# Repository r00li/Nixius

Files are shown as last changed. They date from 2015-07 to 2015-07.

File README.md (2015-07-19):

## Nixius ##
A simple ARM powered Nixie clock.

Nixius

**Features**

 - It's a clock
 - User settable auto turn on/turn off time (can turn off at night)
 - Manual display on/off button
 - Temperature display

**I want it!**

Great! Build it! This project includes everything that you need. A complete PCB, a 3D printable case and firmware source code.

**Instructions**

 1. Download the project
 2. Manufacture the PCB at your favourite PCB fab (I recommend elecrow.com). I've already included the gerbers so you don't even have to use eagle to export them - they are exported for use with elecrow so you may need to export them again if you want to manufacture them somewhere else.
 3. Order the necessary parts listed in bill of materials (I recommend Farnell/Element 14). Nixies themselves can be bought at siberian-shop.com or somewhere else.
 4. Solder everything together
 5. Flash the firmware to the micro. You will need any STM development board (they can be bought at Farnell for less than 10€) with STLINK. You can compile the project using free EmBlocks IDE (now also called EmBitz). It's a GCC based IDE so it should work with other compilers/IDEs as well. If you don't want to compile the project then you can simply used the .hex file in the bin folder. It's configured for use without the temperature sensor. But compiling everything in EmBlocks should only take a few clicks so I recommend that. 
 6. 3D print the case. It's designed to be 3D printable on most popular home 3D printers. 
 7. Assemble everything and enjoy

I am happy to provide any assistance that you may need. 

**More information**

Hackaday.io: https://hackaday.io/project/5543-nixius

My website: http://www.r00li.com

**Tinkering**

I've used many online sources to build this thing. Especially the power supply part and how to drive the Nixies. Do you want to use some of the bits from my design? Go right ahead! Don't want to use IN-1 nixies? You will just need to replace 4 resistors in the center with the correct ones and you'll be fine. And of course use some wire to connect the nixies. 

**License**

Licensed under GNU GPL v3.

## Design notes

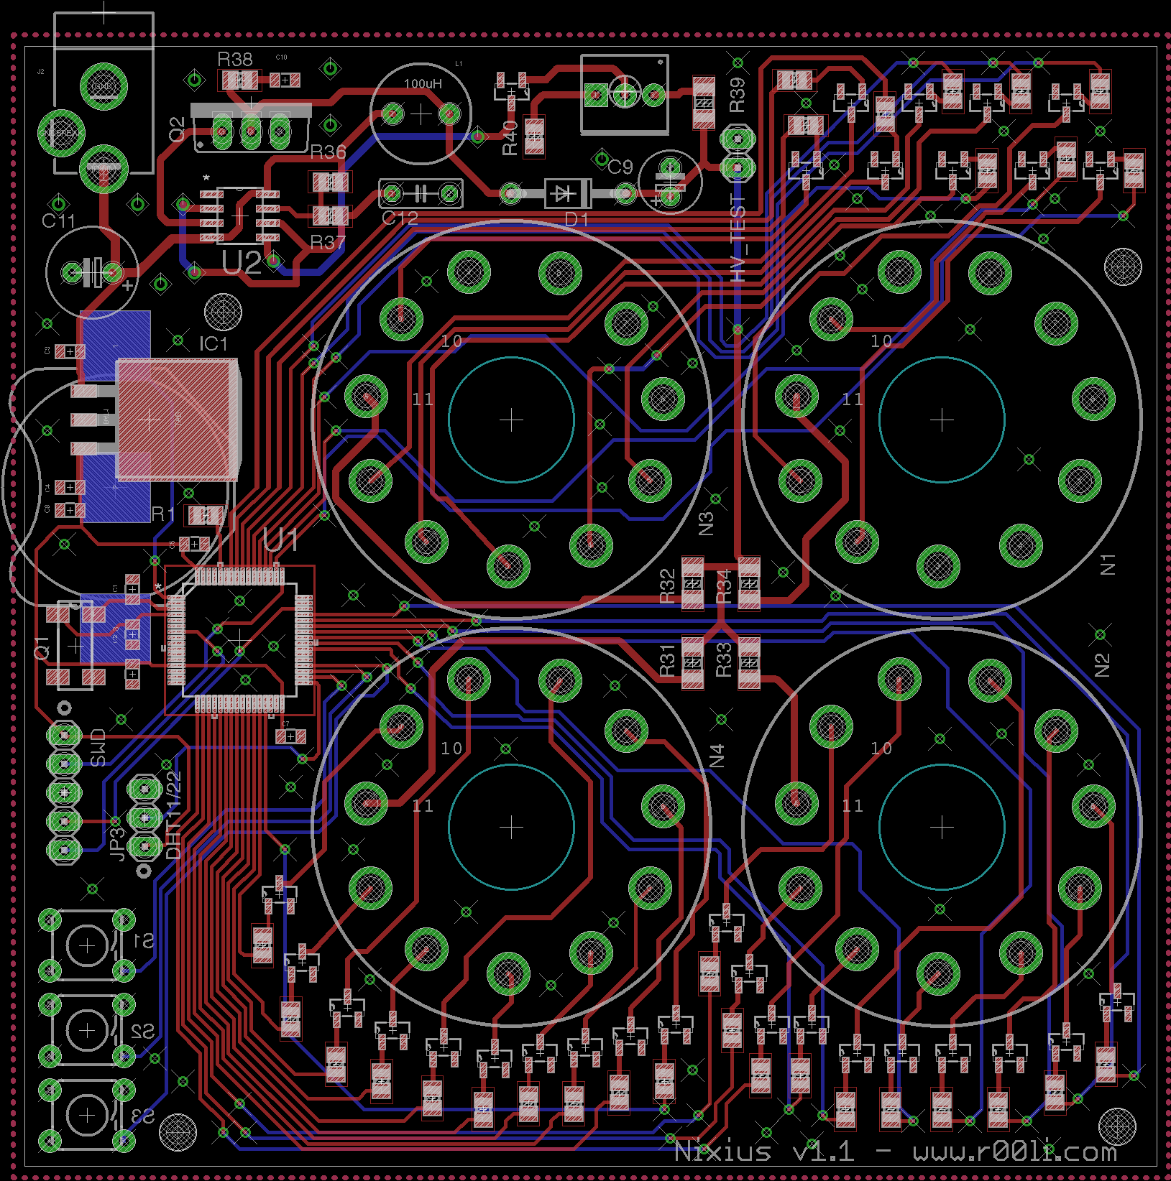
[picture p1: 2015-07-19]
PCB/Nixius_PCB.png

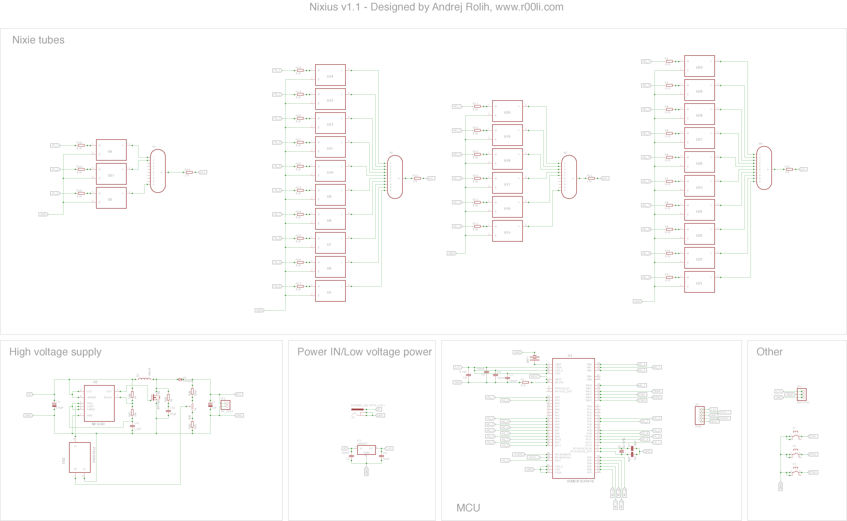
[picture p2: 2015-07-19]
PCB/Nixius.png

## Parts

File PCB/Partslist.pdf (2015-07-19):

Qty | Value | Device | Package | Farnell order code | Parts designators | Description
1 | | SMD Battery holder | 20MM | 2115303 | BAT1 | Battery Holder 20mm
3 | FSM6JH | Switch | TACTILE-‐PTH | 1555983 | S1, S2, S3 | Momentary Switch (through hole) -‐ around 8.5mm height
4 | 100nF | C | 0805 | 1759143 | C3, C5, C6, C7 | Capacitor
1 | 100uH | Inductor | RLB0912 | 1864382 | L1 | Inductor
1 | 10k | R (200V tolerant) | 0805 | 1750767 | R37 | Resistor
1 | 10uF | C | 0805 | 2362101 | C4 | Capacitor
2 | 18pF | C | 0805 | 1740651 | C1, C2 | Capacitor
2 | 1k | R (200V tolerant) | 0805 | 1750754 | R36, R38 | Resistor
1 | 1k | Trimpot (200V tolerant) | 3362U-‐2 | 1141401 | R35 | Trimmer potentiometer
1 | 1uF | C (200V tolerant) | E2,5-‐6 | 2346640 | C9 | Capacitor
1 | 2.2nF | C (200V tolerant) | 050-‐025X075 | 1166065 | C12 | Capacitor
1 | 220k | R (200V tolerant) | 1206 | 2352636 | R39 | Resistor
4 | 27k | R (200V tolerant) | 1206 | 1750855 | R31, R32, R33, R34 | Resistor
1 | 32.7kHZ | Crystal | MC-‐306 | 1712823 | Q1 | Crystal
1 | 4.7uF | C | 0805 | 1759414 | C8 | Capacitor
1 | 470uF | C | E3,5-‐8 | 1907237 | C11 | Capacitor
1 | 47pF | C (200V tolerant) | 0805 | 1284128 | C10 | Capacitor
2 | 510 | R | 0805 | 9334637 | R1, R40 | Resistor
29 | 8.2k | R | 0805 | 2074518 | R2, R3, R4, R5, R6, R7, R8, R9, R10, R11, R12, R13, R14, R15, R16, R17, R18, R19, R20, R21, R22, R23, R24, R25, R26, R27, R28, R29, R30 | Resistor -‐ Parts designators on PCB have been removed
1 | DHT11/22 | Temperature sensor | | / | JP3 | Temperature sensor -‐ DHT11/DHT22 -‐ Optional -‐ You can get it at elecrow
30 | FMMTA42 | FMMTA42 | SOT23 | 9526277 | U3, U4, U5, U6, U7, U8, U9, U10, U11, U12, U13, U14, U15, U16, U17, U18, U19, U20, U21, U22, U23, U24, U25, U26, U27, U28, U29, U30, U31, U32 | NPN Silicon planar high voltage transistor -‐ Parts designators on PCB have been removed
4 | IN-‐1 | IN-‐1 | | / | N1, N2, N3, N4 | IN-‐1: large numeric topview nixie tube -‐ I used Siberian shop (http://www.siberian-‐shop.com/)
1 | IRF730 | IRF730 | TO220 | 8648433 | Q2 | N-‐channel MOSFET
1 | LM2937 | LM2937 | TO263-‐3 | 1469066 | IC1 | LM2937-‐3.3V Voltage regulator
1 | NE555D | NE555D | SOIC8 | 9589880 | U2 | Timer
1 | | POWER_JACKPTH_LOCK | | 1608727 | J2 | Power Jack (standard one, through hole -‐ found anywhere)
1 | STM32F051R4T6 | STM32F051R4T6 | LQFP-‐64 | 2115069 | U1 | MCU, 32BIT, ARM CORTEX-‐M0, 64LQFP
1 | | Header | 1X05 | 9733400 | JP1 | Header (you can probably get them cheaper on ebay) -‐ used for programming
1 | UF4004 | UF4004 | DO41-‐10 | 1467502 | D1 | Diode

You

will

also

need:
-‐

Power

supply

(9V).

Farnell

order

code:

2451882
-‐

PCB

manufacturer.

I

always

use

Elecrow

(http://www.elecrow.com/)

Approximate

cost:
Electronic

components

(without

nixies

and

power

supply)

=

around

40€

(+5€

shipping)
Nixies

=

around

10€

(+20€

shipping)
PCB

Manufacture

=

around

15€

(+15€

shipping)
Temperature

sensor

=

around

7€

(shipping

included

with

PCB

manufacture)
Power

supply

=

around

9€

(shipping

included

with

electronic

components)

Total

cost

=

around

80€

(around

120€

with

shipping)

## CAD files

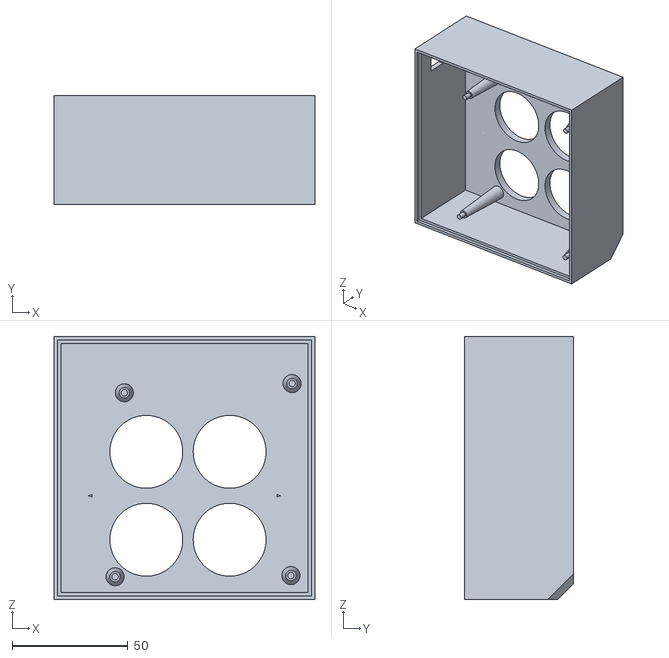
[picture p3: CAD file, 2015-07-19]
Case/Nixius_case.stl
112.8 x 47.3 x 113.8

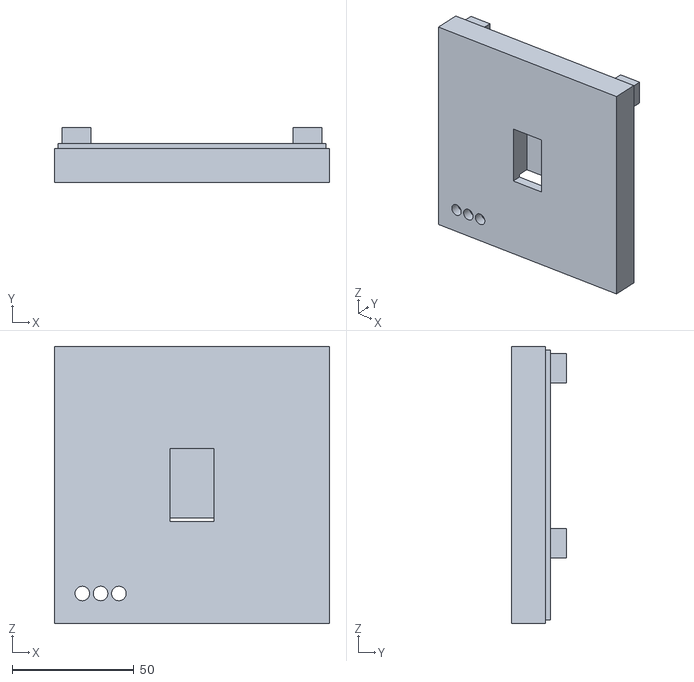
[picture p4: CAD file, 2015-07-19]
Case/Nixius_back.stl
112.8 x 22.5 x 113.8

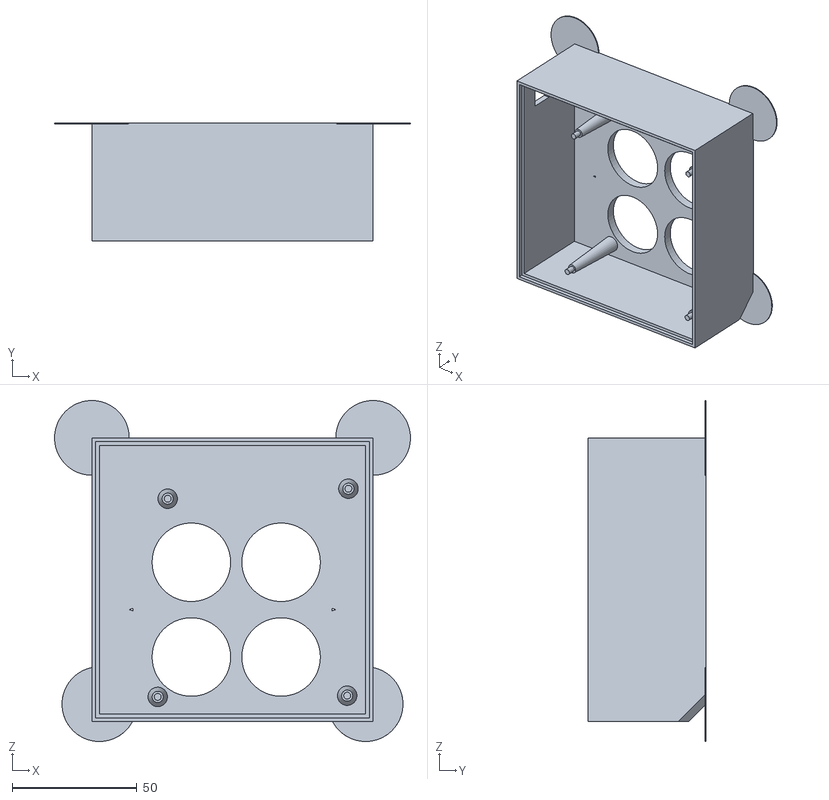
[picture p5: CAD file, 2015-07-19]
Case/Nixius_case_mouse_ears.stl
142.8 x 47.3 x 136.8

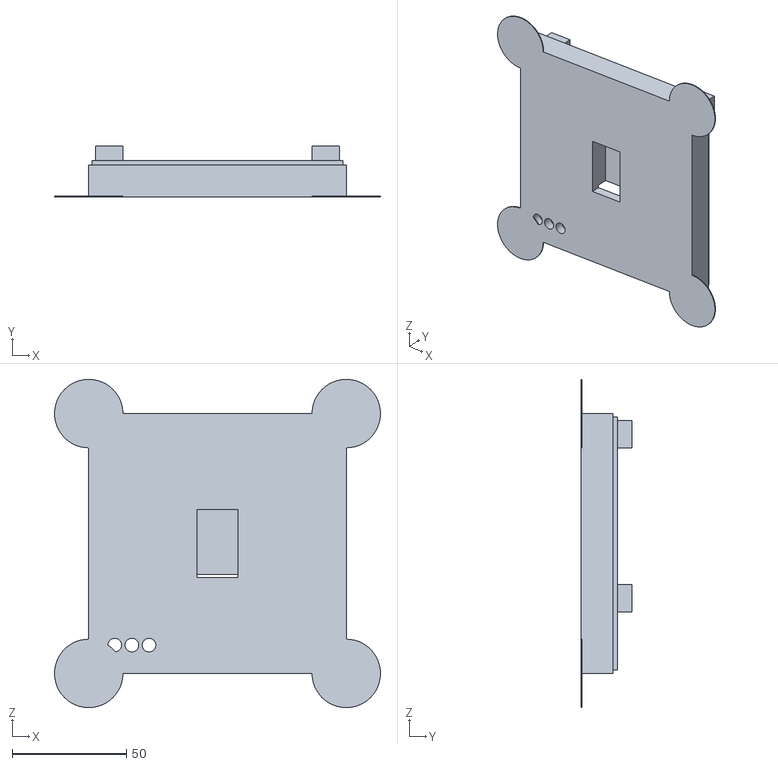
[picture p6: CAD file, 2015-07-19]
Case/Nixius_back_mouse_ears.stl
142.8 x 22.5 x 143.8

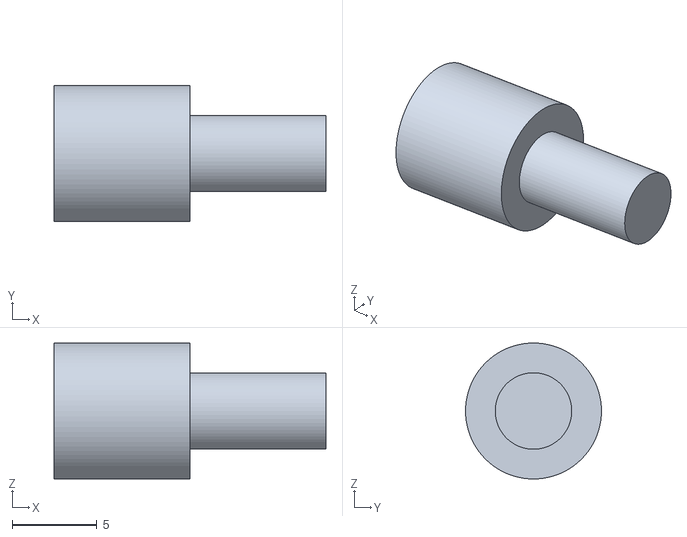
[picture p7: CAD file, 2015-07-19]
Case/Nixius_button.stl
16.0 x 8.00 x 8.00

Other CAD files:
Case/Nixius_case.ipt

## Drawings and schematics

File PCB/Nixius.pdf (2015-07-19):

# Nixie tubes

# Nixius v1.1 - Designed by Andrej Rolih, www.r00li.com

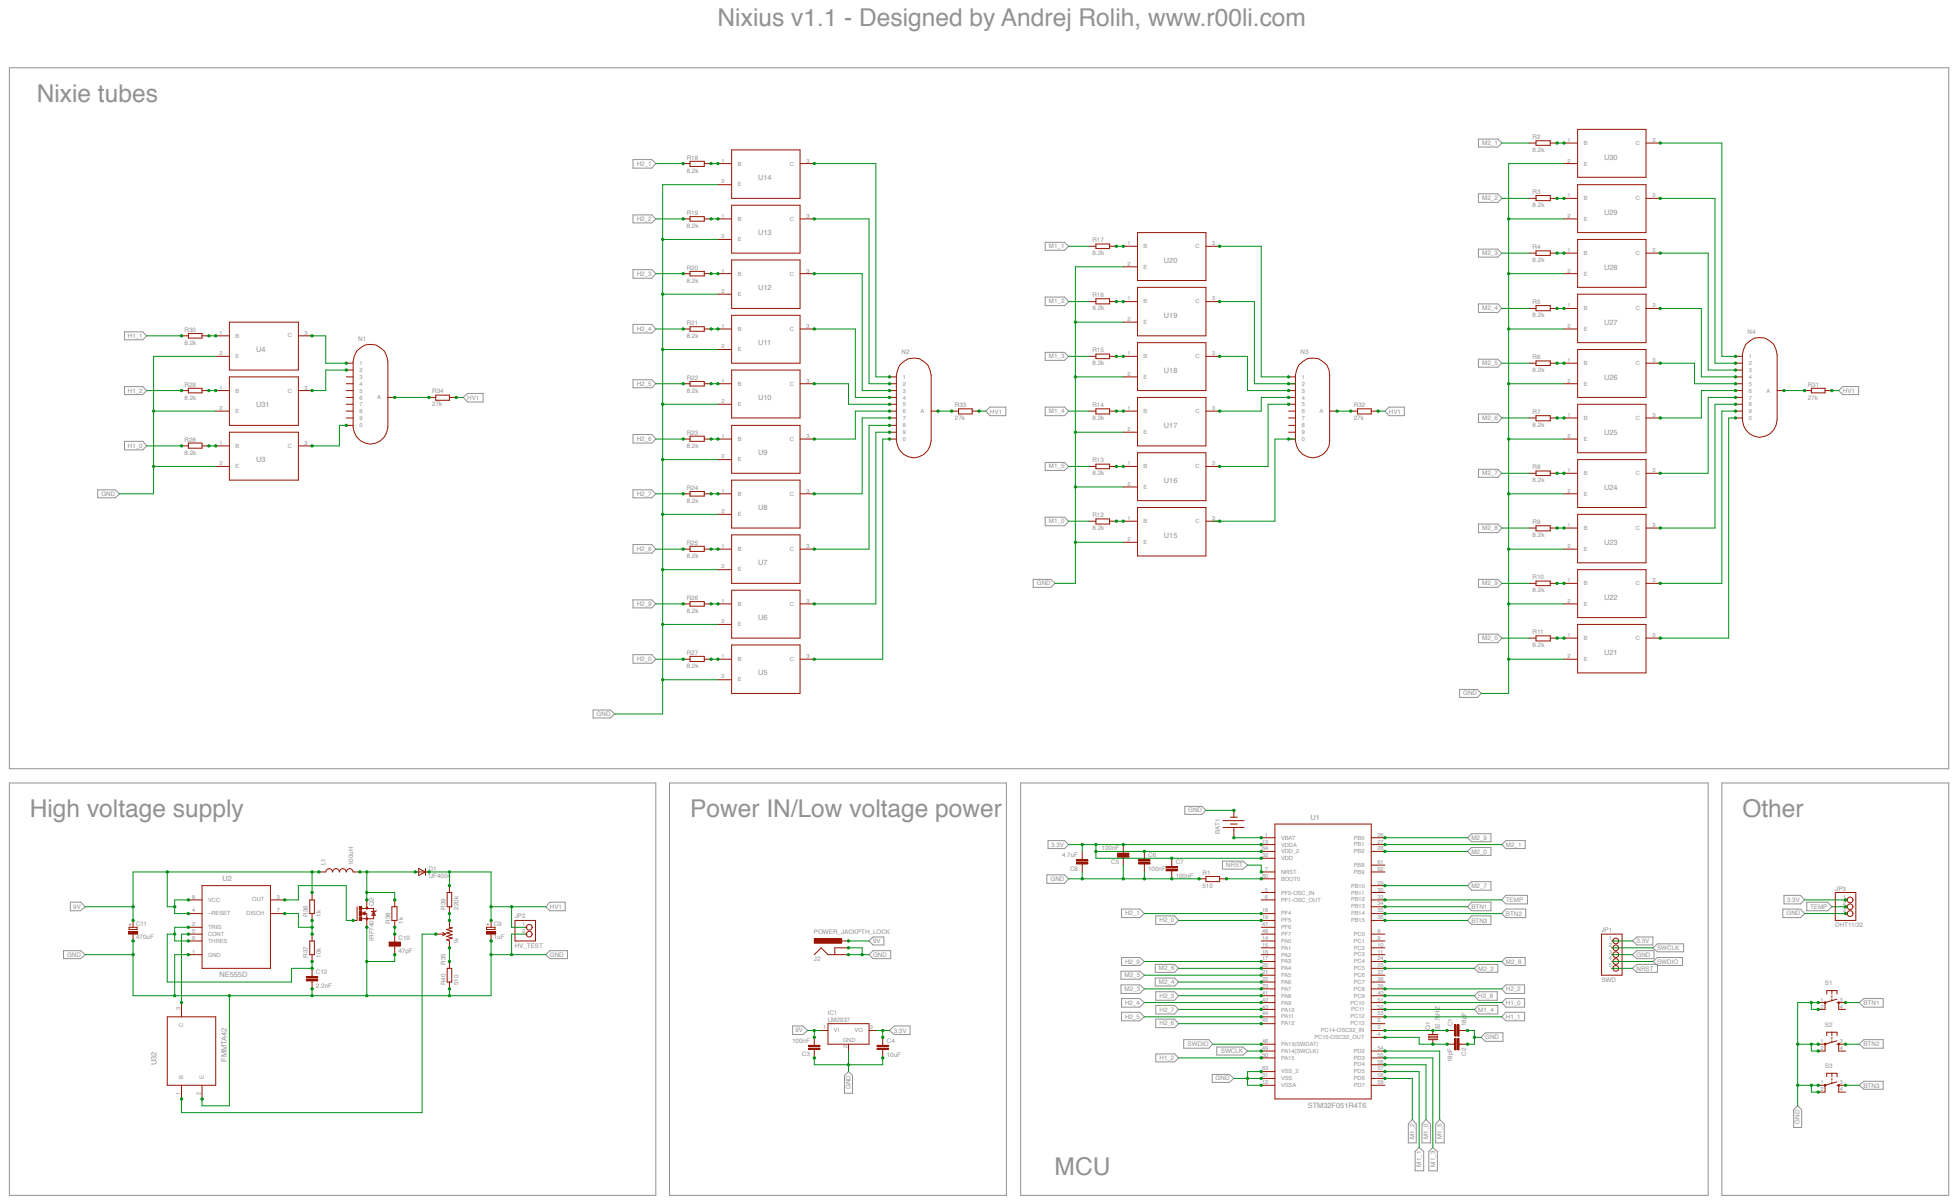
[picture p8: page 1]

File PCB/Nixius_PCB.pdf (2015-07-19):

U2

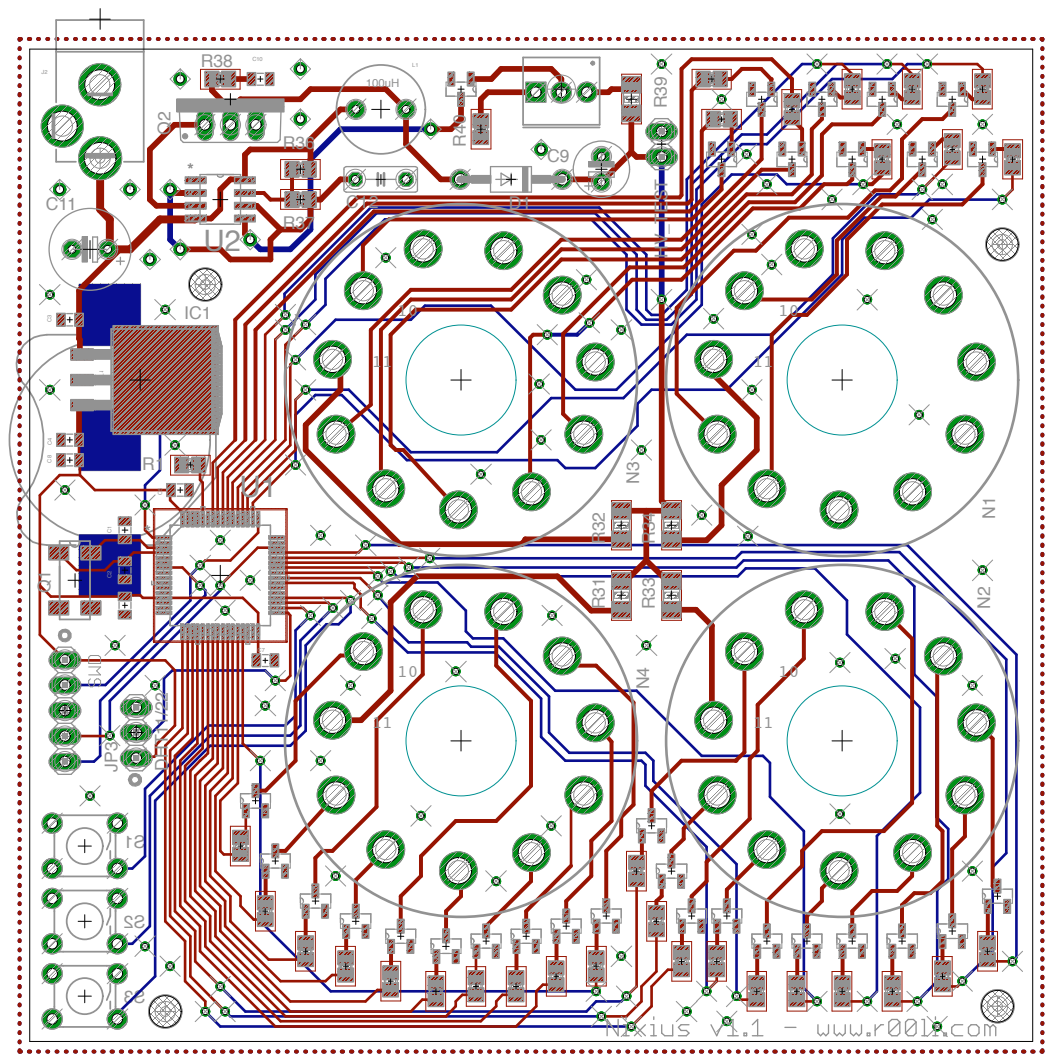
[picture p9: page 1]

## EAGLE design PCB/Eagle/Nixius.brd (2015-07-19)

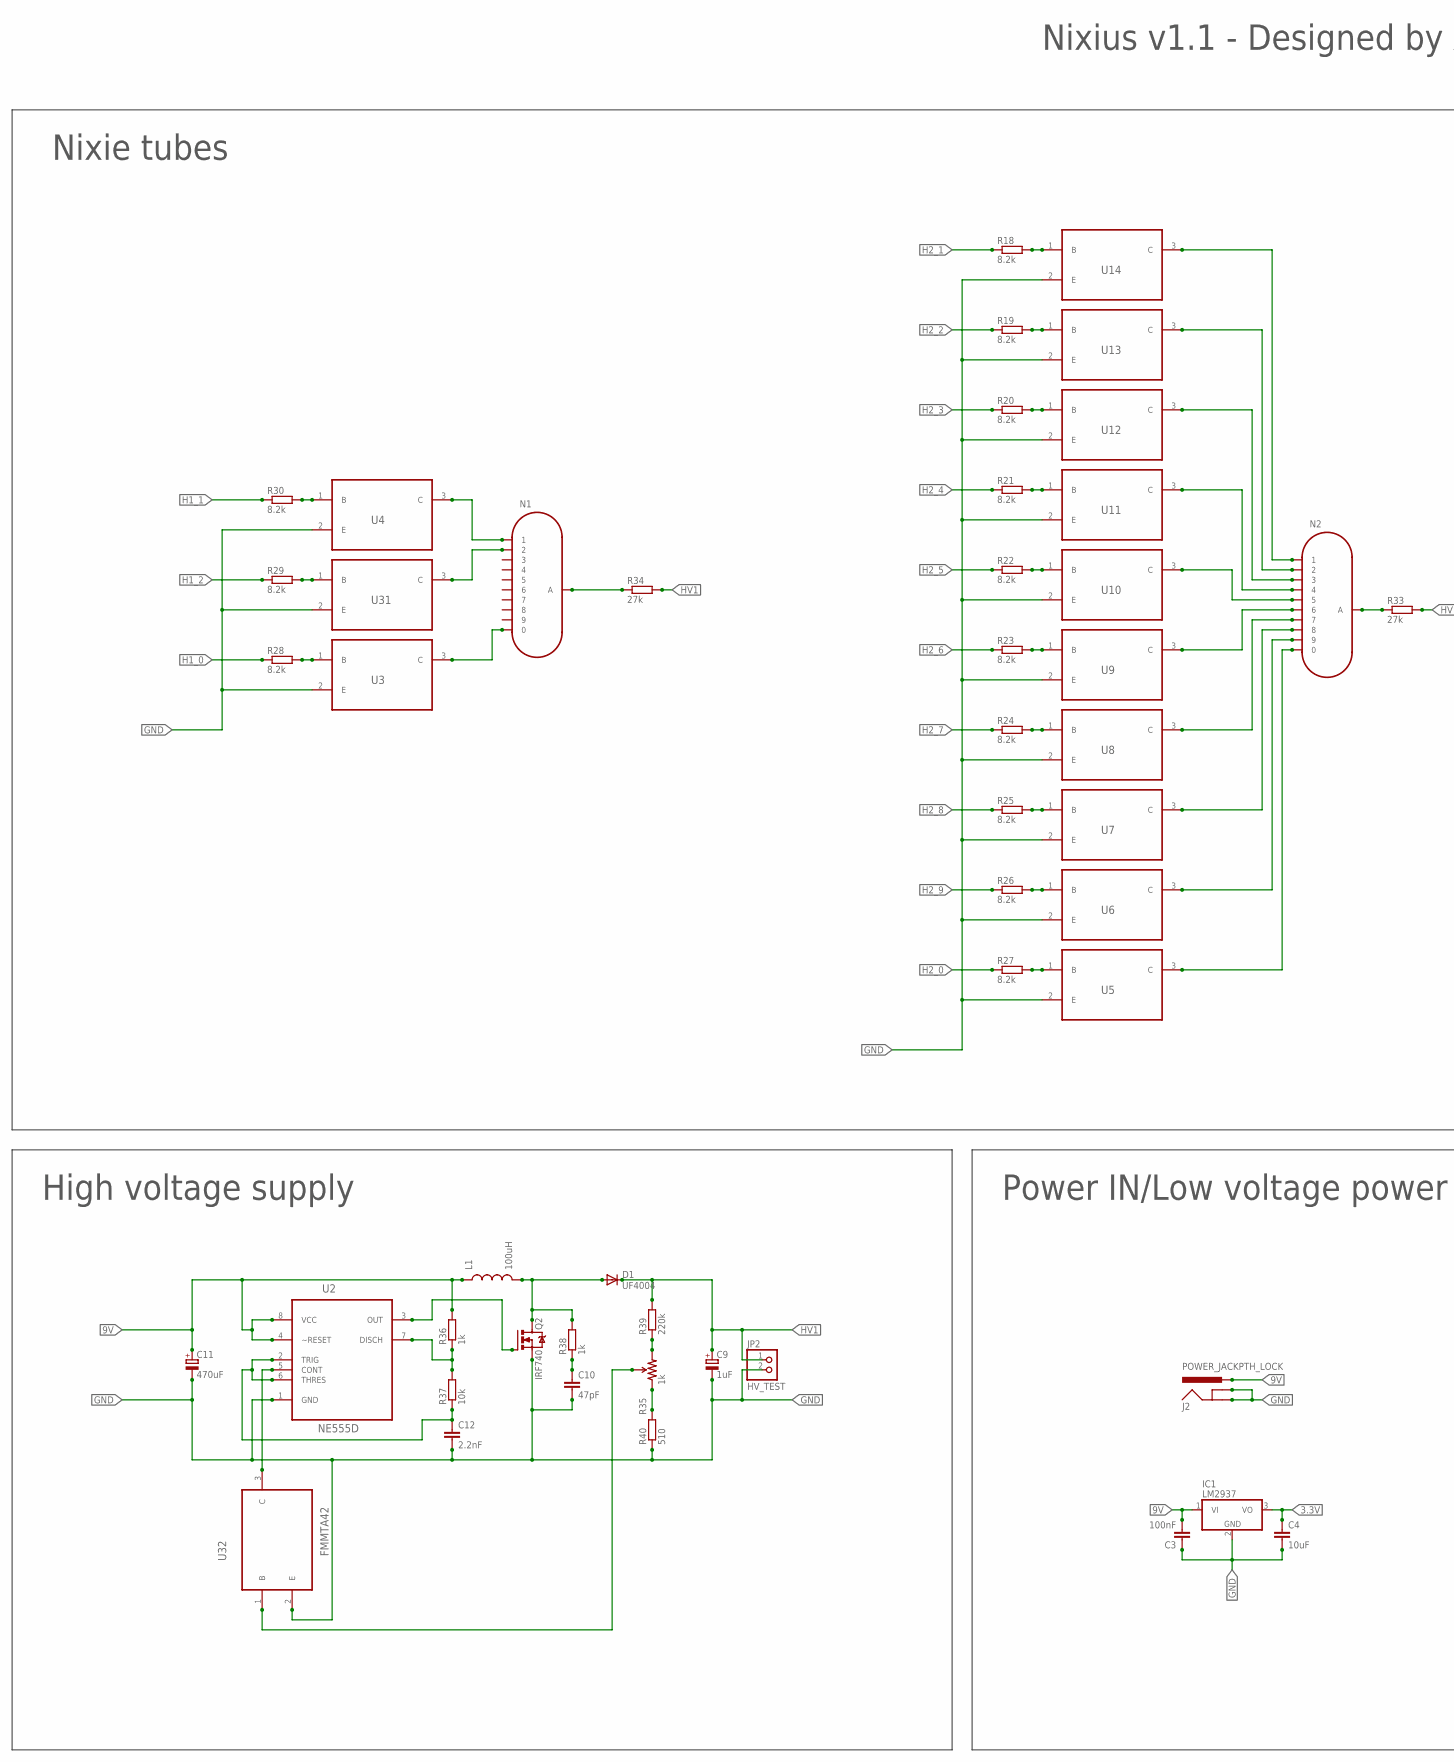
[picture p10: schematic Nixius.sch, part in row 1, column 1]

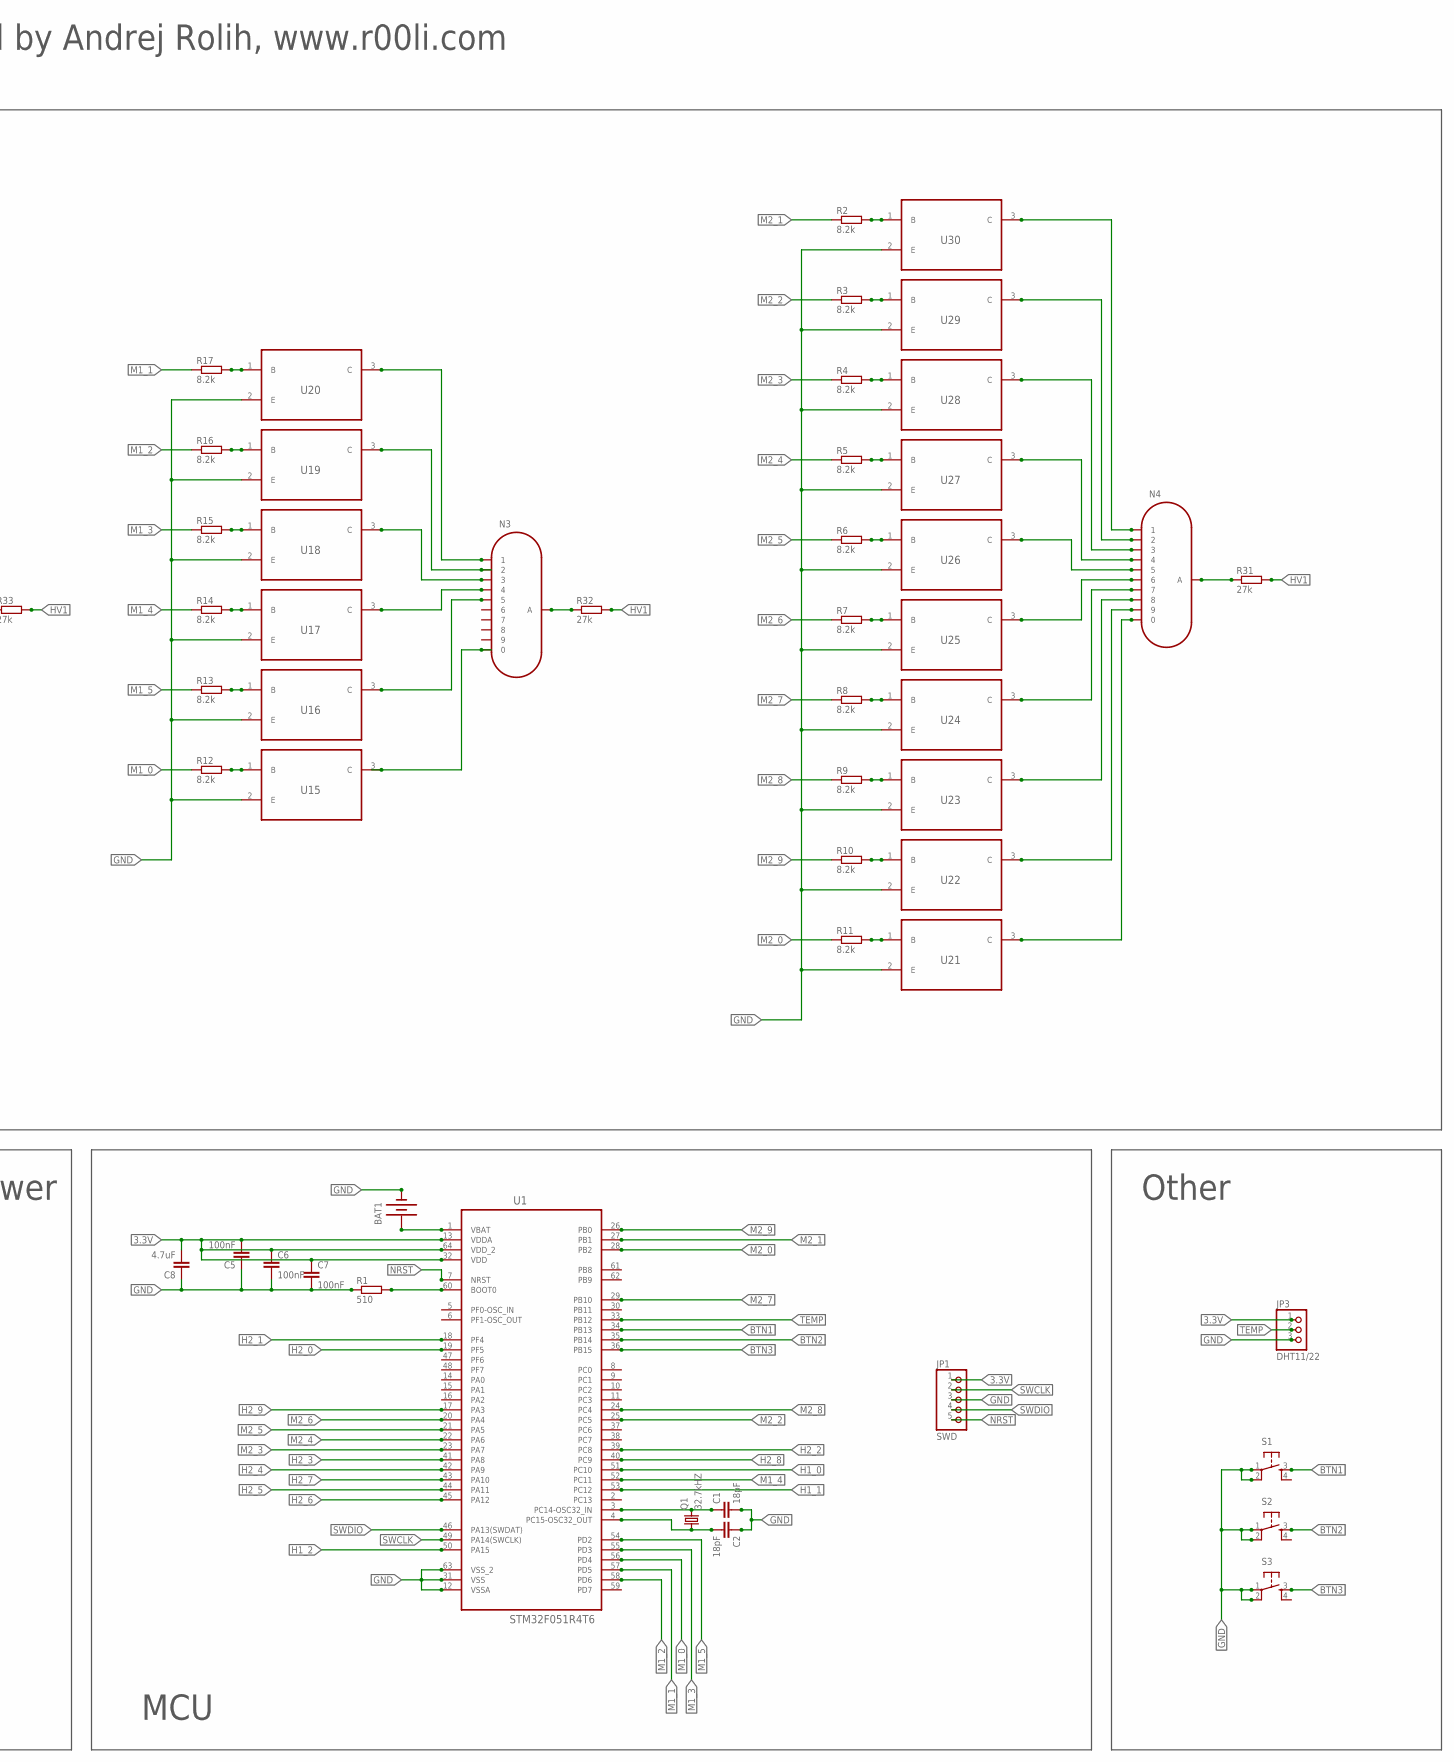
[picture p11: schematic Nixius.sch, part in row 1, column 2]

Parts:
BAT1: BATTERY20SMD; BATTCON_20MM
C1, C2: 18pF; 0805
C3, C5, C6, C7: 100nF; 0805
C4: 10uF; 0805
C8: 4.7uF; 0805
C9: 1uF; E2,5-6
C10: 47pF; 0805
C11: 470uF; E3,5-8
C12: 2.2nF; C050-025X075
D1: UF4004; DO41-10
IC1: LM2937; TO263-3
J2: POWER_JACKPTH_LOCK; POWER_JACK_PTH_LOCK
JP1: SWD; 1X05
JP2: HV_TEST; 1X02
JP3: DHT11/22; 1X03
L1: 100uH; RLB0912
N1, N2, N3, N4: IN-1
Q1: 32.7kHZ; MC-306
Q2: IRF740; TO220BV
R1, R40: 510; R0805
R2, R3, R4, R5, R6, R7, R8, R9, R10, R11, R12, R13, R14, R15, R16, R17, R18, R19, R20, R21, R22, R23, R24, R25, R26, R27, R28, R29, R30: 8.2k; R0805
R31, R32, R33, R34: 27k; R1206
R35: 1k; 3362U-2
R36, R38: 1k; R0805
R37: 10k; R0805
R39: 220k; R1206
S1, S2, S3: TAC_SWITCHPTH; TACTILE-PTH
U1: STM32F051R4T6; QFP50P1200X1200X160-64N
U2: NE555D; SOIC127P600X175-8N
U3, U4, U5, U6, U7, U8, U9, U10, U11, U12, U13, U14, U15, U16, U17, U18, U19, U20, U21, U22, U23, U24, U25, U26, U27, U28, U29, U30, U31, U32: FMMTA42; SOT95P240X110-3N

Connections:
3.3V: C4.1, C5.2, C6.1, C7.1, C8.2, IC1.3 (VO), JP1.1, JP3.1, U1.13 (VDDA), U1.32 (VDD), U1.64 (VDD_2)
9V: C3.2, C11.+, IC1.1 (VI), J2.PWR, L1.1, R36.2, U2.4 (~RESET), U2.8 (VCC)
BTN1: S1.3, U1.34 (PB13)
BTN2: S2.3, U1.35 (PB14)
BTN3: S3.3, U1.36 (PB15)
GND: BAT1.2 (-), C1.2, C2.1, C3.1, C4.2, C5.1, C6.2, C7.2, C8.1, C9.-, C10.2, C11.-, C12.2, IC1.2 (GND), J2.GND, J2.GNDBREAK, JP1.3, JP2.2, JP3.3, Q2.S, R1.1, R40.1, S1.1, S1.2, S2.1, S2.2, S3.1, S3.2, U1.12 (VSSA), U1.31 (VSS), U1.63 (VSS_2), U2.1 (GND), U3.2 (E), U4.2 (E), U5.2 (E), U6.2 (E), U7.2 (E), U8.2 (E), U9.2 (E), U10.2 (E), U11.2 (E), U12.2 (E), U13.2 (E), U14.2 (E), U15.2 (E), U16.2 (E), U17.2 (E), U18.2 (E), U19.2 (E), U20.2 (E), U21.2 (E), U22.2 (E), U23.2 (E), U24.2 (E), U25.2 (E), U26.2 (E), U27.2 (E), U28.2 (E), U29.2 (E), U30.2 (E), U31.2 (E), U32.2 (E)
H1_0: R28.1, U1.51 (PC10)
H1_1: R30.1, U1.53 (PC12)
H1_2: R29.1, U1.50 (PA15)
H2_0: R27.1, U1.19 (PF5)
H2_1: R18.1, U1.18 (PF4)
H2_2: R19.1, U1.39 (PC8)
H2_3: R20.1, U1.41 (PA8)
H2_4: R21.1, U1.42 (PA9)
H2_5: R22.1, U1.44 (PA11)
H2_6: R23.1, U1.45 (PA12)
H2_7: R24.1, U1.43 (PA10)
H2_8: R25.1, U1.40 (PC9)
H2_9: R26.1, U1.17 (PA3)
HV1: C9.+, D1.C, JP2.1, R31.2, R32.2, R33.2, R34.2, R39.2
M1_0: R12.1, U1.56 (PD4)
M1_1: R17.1, U1.57 (PD5)
M1_2: R16.1, U1.58 (PD6)
M1_3: R15.1, U1.55 (PD3)
M1_4: R14.1, U1.52 (PC11)
M1_5: R13.1, U1.54 (PD2)
M2_0: R11.1, U1.28 (PB2)
M2_1: R2.1, U1.27 (PB1)
M2_2: R3.1, U1.25 (PC5)
M2_3: R4.1, U1.23 (PA7)
M2_4: R5.1, U1.22 (PA6)
M2_5: R6.1, U1.21 (PA5)
M2_6: R7.1, U1.20 (PA4)
M2_7: R8.1, U1.29 (PB10)
M2_8: R9.1, U1.24 (PC4)
M2_9: R10.1, U1.26 (PB0)
unnamed: N1.0, U3.3 (C)
unnamed: N1.2, U31.3 (C)
unnamed: N1.1, U4.3 (C)
unnamed: N2.0, U5.3 (C)
unnamed: N2.9, U6.3 (C)
unnamed: N2.8, U7.3 (C)
unnamed: N2.7, U8.3 (C)
unnamed: N2.6, U9.3 (C)
unnamed: N2.5, U10.3 (C)
unnamed: N2.4, U11.3 (C)
unnamed: N2.3, U12.3 (C)
unnamed: N2.2, U13.3 (C)
unnamed: N2.1, U14.3 (C)
unnamed: N3.0, U15.3 (C)
unnamed: N3.5, U16.3 (C)
unnamed: N3.4, U17.3 (C)
unnamed: N3.3, U18.3 (C)
unnamed: N3.2, U19.3 (C)
unnamed: N3.1, U20.3 (C)
unnamed: N4.0, U21.3 (C)
unnamed: N4.9, U22.3 (C)
unnamed: N4.8, U23.3 (C)
unnamed: N4.7, U24.3 (C)
unnamed: N4.6, U25.3 (C)
unnamed: N4.5, U26.3 (C)
unnamed: N4.4, U27.3 (C)
unnamed: N4.3, U28.3 (C)
unnamed: N4.2, U29.3 (C)
unnamed: N4.1, U30.3 (C)
unnamed: BAT1.1 (+), U1.1 (VBAT)
unnamed: C1.1, Q1.4 (2), U1.3 (PC14-OSC32_IN)
unnamed: C2.2, Q1.1, U1.4 (PC15-OSC32_OUT)
unnamed: R1.2, U1.60 (BOOT0)
unnamed: R30.2, U4.1 (B)
unnamed: R29.2, U31.1 (B)
unnamed: R28.2, U3.1 (B)
unnamed: R18.2, U14.1 (B)
unnamed: R19.2, U13.1 (B)
unnamed: R20.2, U12.1 (B)
unnamed: R21.2, U11.1 (B)
unnamed: R22.2, U10.1 (B)
unnamed: R23.2, U9.1 (B)
unnamed: R24.2, U8.1 (B)
unnamed: R25.2, U7.1 (B)
unnamed: R26.2, U6.1 (B)
unnamed: R27.2, U5.1 (B)
unnamed: R17.2, U20.1 (B)
unnamed: R16.2, U19.1 (B)
unnamed: R15.2, U18.1 (B)
unnamed: R14.2, U17.1 (B)
unnamed: R13.2, U16.1 (B)
unnamed: R12.2, U15.1 (B)
unnamed: R2.2, U30.1 (B)
unnamed: R3.2, U29.1 (B)
unnamed: R4.2, U28.1 (B)
unnamed: R5.2, U27.1 (B)
unnamed: R6.2, U26.1 (B)
unnamed: R7.2, U25.1 (B)
unnamed: R8.2, U24.1 (B)
unnamed: R9.2, U23.1 (B)
unnamed: R10.2, U22.1 (B)
unnamed: R11.2, U21.1 (B)
unnamed: N1.A, R34.1
unnamed: N3.A, R32.1
unnamed: R36.1, R37.2, U2.7 (DISCH)
unnamed: U2.5 (CONT), U32.3 (C)
unnamed: C12.1, R37.1, U2.2 (TRIG), U2.6 (THRES)
unnamed: Q2.G, U2.3 (OUT)
unnamed: D1.A, L1.2, Q2.D, R38.2
unnamed: C10.1, R38.1
unnamed: R35.3 (CW), R39.1
unnamed: R35.1 (CCW), R40.2
unnamed: N2.A, R33.1
unnamed: R35.2 (WIPER), U32.1 (B)
unnamed: N4.A, R31.1
NRST: JP1.5, U1.7 (NRST)
SWCLK: JP1.2, U1.49 (PA14(SWCLK))
SWDIO: JP1.4, U1.46 (PA13(SWDAT))
TEMP: JP3.2, U1.33 (PB12)

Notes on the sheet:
Nixie tubes
High voltage supply
Power IN/Low voltage power
MCU
Other
Nixius v1.1 - Designed by Andrej Rolih, www.r00li.com

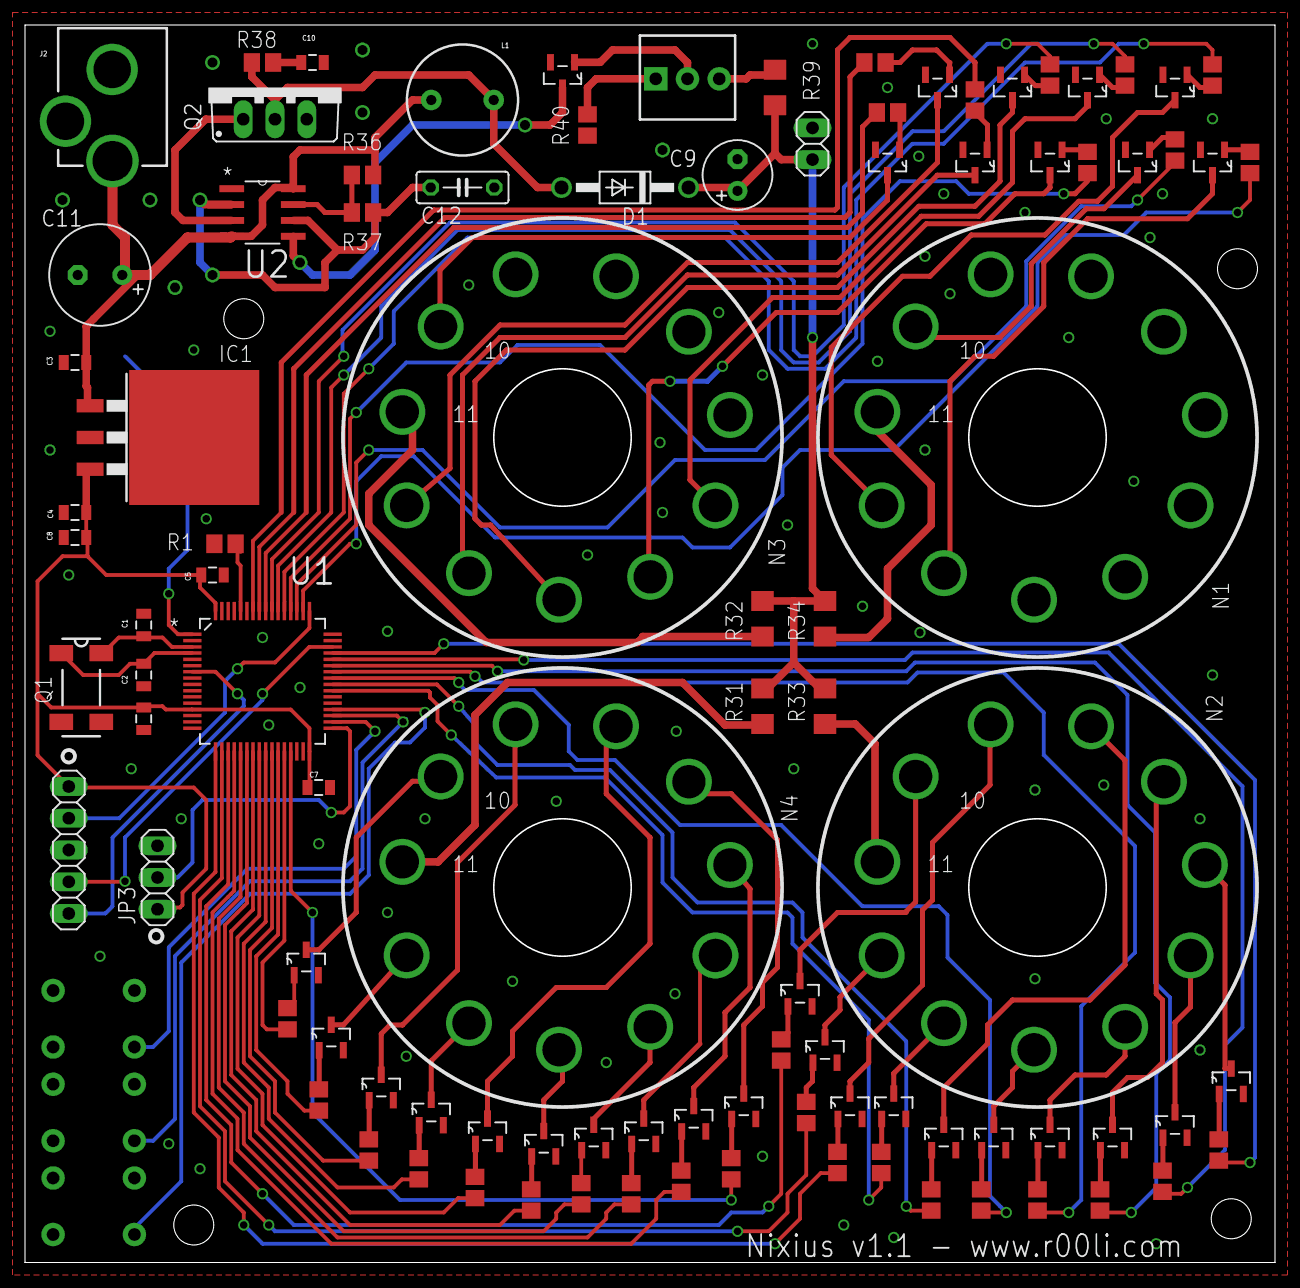
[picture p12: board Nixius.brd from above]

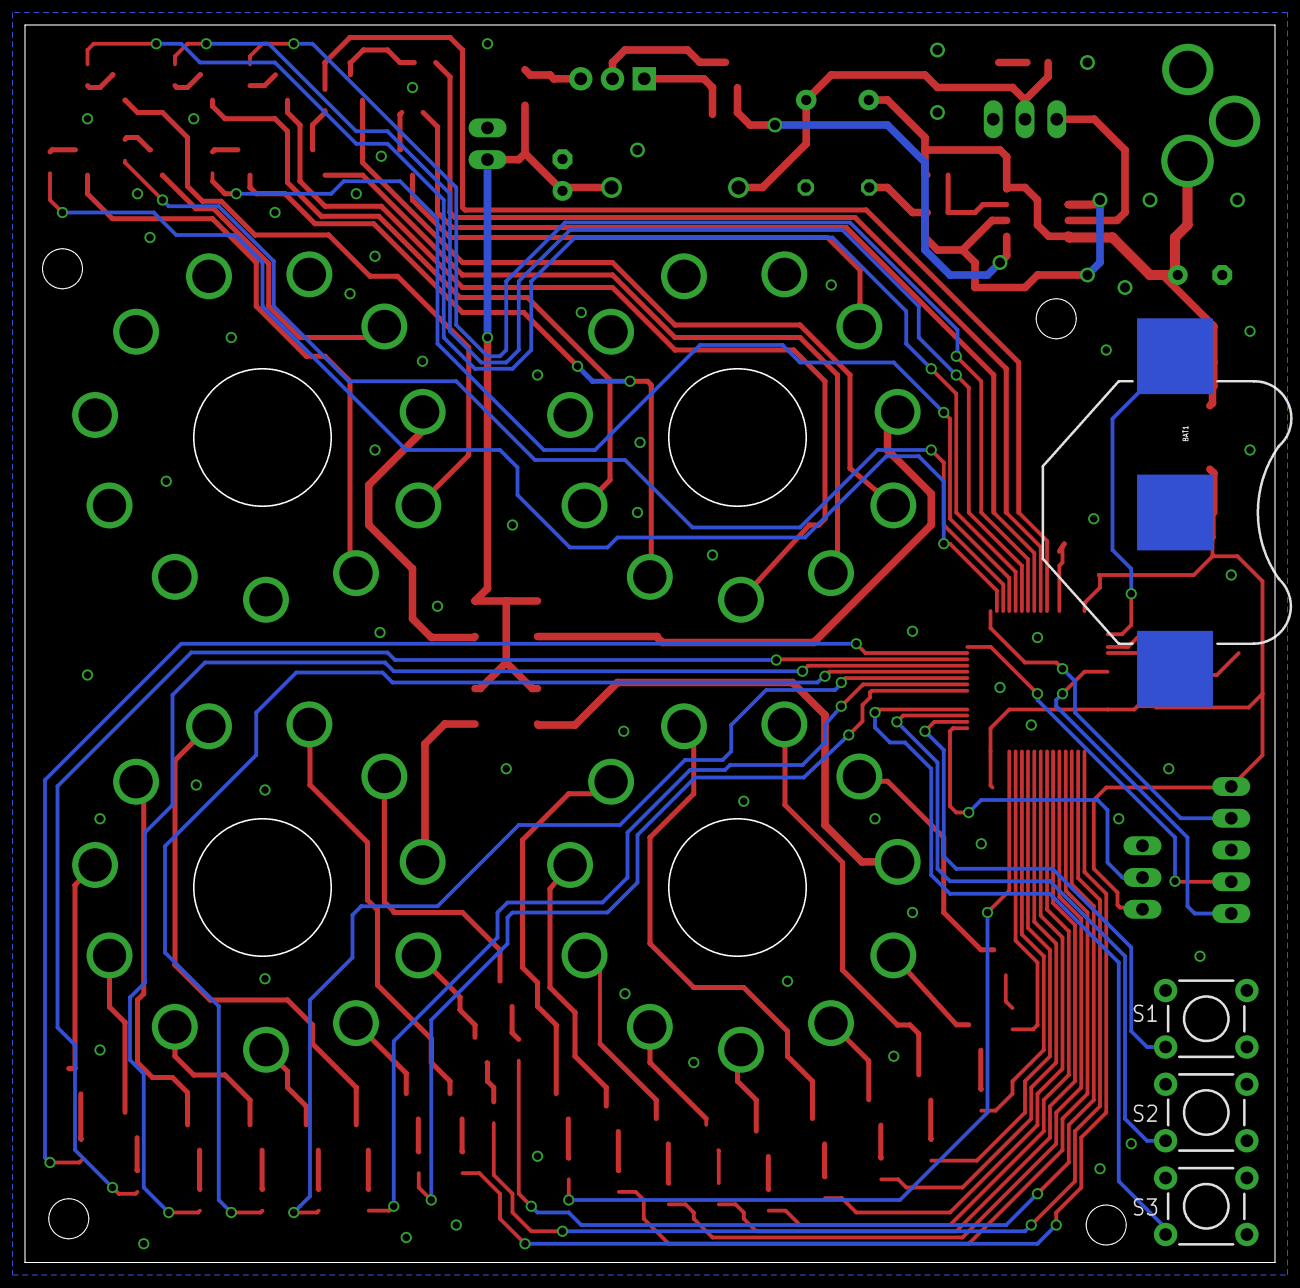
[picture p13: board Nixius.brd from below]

Board: 2 copper layers, 100.0 x 99.0 mm, 101 parts (4 on the bottom side), 115 nets.

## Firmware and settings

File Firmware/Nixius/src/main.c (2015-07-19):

/*
**
**                           Main.c
**
**
**********************************************************************/
/*

 Nixius
 Created by: Andrej Rolih (www.r00li.com)
 For licensing see included License file
 Revision 1.0

**********************************************************************/

#include "stm32f0xx_conf.h"
#include "essentials.h"
#include "dht22.h"

#define Pin_H1_0 GPIOC,GPIO_Pin_10
#define Pin_H1_1 GPIOC,GPIO_Pin_12
#define Pin_H1_2 GPIOA,GPIO_Pin_15

#define Pin_H2_0 GPIOF,GPIO_Pin_5
#define Pin_H2_1 GPIOF,GPIO_Pin_4
#define Pin_H2_2 GPIOC,GPIO_Pin_8
#define Pin_H2_3 GPIOA,GPIO_Pin_8
#define Pin_H2_4 GPIOA,GPIO_Pin_9
#define Pin_H2_5 GPIOA,GPIO_Pin_11
#define Pin_H2_6 GPIOA,GPIO_Pin_12
#define Pin_H2_7 GPIOA,GPIO_Pin_10
#define Pin_H2_8 GPIOC,GPIO_Pin_9
#define Pin_H2_9 GPIOA,GPIO_Pin_3

#define Pin_M1_0 GPIOB,GPIO_Pin_4
#define Pin_M1_1 GPIOB,GPIO_Pin_5
#define Pin_M1_2 GPIOB,GPIO_Pin_6
#define Pin_M1_3 GPIOB,GPIO_Pin_3
#define Pin_M1_4 GPIOC,GPIO_Pin_11
#define Pin_M1_5 GPIOD,GPIO_Pin_2

#define Pin_M2_0 GPIOB,GPIO_Pin_2
#define Pin_M2_1 GPIOB,GPIO_Pin_1
#define Pin_M2_2 GPIOC,GPIO_Pin_5
#define Pin_M2_3 GPIOA,GPIO_Pin_7
#define Pin_M2_4 GPIOA,GPIO_Pin_6
#define Pin_M2_5 GPIOA,GPIO_Pin_5
#define Pin_M2_6 GPIOA,GPIO_Pin_4
#define Pin_M2_7 GPIOB,GPIO_Pin_10
#define Pin_M2_8 GPIOC,GPIO_Pin_4
#define Pin_M2_9 GPIOB,GPIO_Pin_0

#define Tube_H1 0
#define Tube_H2 1
#define Tube_M1 2
#define Tube_M2 3

#define Pin_Button_1 GPIOB,GPIO_Pin_13
#define Pin_Button_2 GPIOB,GPIO_Pin_14
#define Pin_Button_3 GPIOB,GPIO_Pin_15

#define State_Clock 0
#define State_Off 1
#define State_Temperature 2

// Temeprature sensor settings - enable the sensor and select sensor type
//#define TEMP_SENSOR_ENABLE 1
//#define TEMP_SENSOR_DHT11 1
#define TEMP_SENSOR_DHT22 1

volatile int button1Flag = 0;
volatile int button2Flag = 0;
volatile int button3Flag = 0;
volatile unsigned long button1PressStart = 0;
volatile unsigned long button2PressStart = 0;
volatile unsigned long button3PressStart = 0;

volatile unsigned long secondsPassed = 0;

// State configuration settings
int state = State_Clock;
int autoPowerOnEnabled;
int autoPowerOnHours;
int autoPowerOnMinutes;
int autoPowerOffHours;
int autoPowerOffMinutes;


void EXTI4_15_IRQHandler()
{
    if (EXTI_GetITStatus(EXTI_Line13) != RESET)
    {
        delay(100);
        if (GPIO_ReadInputDataBit(Pin_Button_1) == RESET)
        {
            button1Flag = 1;
            button1PressStart = millis();
        }
        EXTI_ClearITPendingBit(EXTI_Line13);
    }
    else if (EXTI_GetITStatus(EXTI_Line14) != RESET)
    {
        delay(100);
        if (GPIO_ReadInputDataBit(Pin_Button_2) == RESET)
        {
            button2Flag = 1;
            button2PressStart = millis();
        }
        EXTI_ClearITPendingBit(EXTI_Line14);
    }
    else if (EXTI_GetITStatus(EXTI_Line15) != RESET)
    {
        delay(100);
        if (GPIO_ReadInputDataBit(Pin_Button_3) == RESET)
        {
            button3Flag = 1;
            button3PressStart = millis();
        }
        EXTI_ClearITPendingBit(EXTI_Line15);
    }
}

void RTC_IRQHandler()
{
    if(RTC_GetITStatus(RTC_IT_ALRA) != RESET)
    {
        secondsPassed++;

        RTC_ClearITPendingBit(RTC_IT_ALRA);
        EXTI_ClearITPendingBit(EXTI_Line17);
    }
}

void blankTube(int tube)
{
    if (tube == Tube_H1)
    {
        GPIO_ResetBits(Pin_H1_0);
        GPIO_ResetBits(Pin_H1_1);
        GPIO_ResetBits(Pin_H1_2);
    }
    else if (tube == Tube_H2)
    {
        GPIO_ResetBits(Pin_H2_0);
        GPIO_ResetBits(Pin_H2_1);
        GPIO_ResetBits(Pin_H2_2);
        GPIO_ResetBits(Pin_H2_3);
        GPIO_ResetBits(Pin_H2_4);
        GPIO_ResetBits(Pin_H2_5);
        GPIO_ResetBits(Pin_H2_6);
        GPIO_ResetBits(Pin_H2_7);
        GPIO_ResetBits(Pin_H2_8);
        GPIO_ResetBits(Pin_H2_9);
    }
    else if (tube == Tube_M1)
    {
        GPIO_ResetBits(Pin_M1_0);
        GPIO_ResetBits(Pin_M1_1);
        GPIO_ResetBits(Pin_M1_2);
        GPIO_ResetBits(Pin_M1_3);
        GPIO_ResetBits(Pin_M1_4);
        GPIO_ResetBits(Pin_M1_5);
    }
    else if (tube == Tube_M2)
    {
        GPIO_ResetBits(Pin_M2_0);
        GPIO_ResetBits(Pin_M2_1);
        GPIO_ResetBits(Pin_M2_2);
        GPIO_ResetBits(Pin_M2_3);
        GPIO_ResetBits(Pin_M2_4);
        GPIO_ResetBits(Pin_M2_5);
        GPIO_ResetBits(Pin_M2_6);
        GPIO_ResetBits(Pin_M2_7);
        GPIO_ResetBits(Pin_M2_8);
        GPIO_ResetBits(Pin_M2_9);
    }
}

void displayNumber(int tube, int number)
{
    blankTube(tube);

    if (tube == Tube_H1)
    {
        switch (number)
        {
            case 0: GPIO_SetBits(Pin_H1_0); break;
            case 1: GPIO_SetBits(Pin_H1_1); break;
            case 2: GPIO_SetBits(Pin_H1_2); break;
        }
    }
    else if (tube == Tube_H2)
    {
        switch (number)
        {
            case 0: GPIO_SetBits(Pin_H2_0); break;
            case 1: GPIO_SetBits(Pin_H2_1); break;
            case 2: GPIO_SetBits(Pin_H2_2); break;
            case 3: GPIO_SetBits(Pin_H2_3); break;
            case 4: GPIO_SetBits(Pin_H2_4); break;
            case 5: GPIO_SetBits(Pin_H2_5); break;
            case 6: GPIO_SetBits(Pin_H2_6); break;
            case 7: GPIO_SetBits(Pin_H2_7); break;
            case 8: GPIO_SetBits(Pin_H2_8); break;
            case 9: GPIO_SetBits(Pin_H2_9); break;
        }
    }
    else if (tube == Tube_M1)
    {
        switch (number)
        {
            case 0: GPIO_SetBits(Pin_M1_0); break;
            case 1: GPIO_SetBits(Pin_M1_1); break;
            case 2: GPIO_SetBits(Pin_M1_2); break;
            case 3: GPIO_SetBits(Pin_M1_3); break;
            case 4: GPIO_SetBits(Pin_M1_4); break;
            case 5: GPIO_SetBits(Pin_M1_5); break;
        }
    }
    else if (tube == Tube_M2)
    {
        switch (number)
        {
            case 0: GPIO_SetBits(Pin_M2_0); break;
            case 1: GPIO_SetBits(Pin_M2_1); break;
            case 2: GPIO_SetBits(Pin_M2_2); break;
            case 3: GPIO_SetBits(Pin_M2_3); break;
            case 4: GPIO_SetBits(Pin_M2_4); break;
            case 5: GPIO_SetBits(Pin_M2_5); break;
            case 6: GPIO_SetBits(Pin_M2_6); break;
            case 7: GPIO_SetBits(Pin_M2_7); break;
            case 8: GPIO_SetBits(Pin_M2_8); break;
            case 9: GPIO_SetBits(Pin_M2_9); break;
        }
    }
}

int numbericInput(int tubeConfig, int minimum, int maximum)
{
    int number = minimum;
    char buffer[4];

    blankTube(Tube_H1);
    blankTube(Tube_H2);
    blankTube(Tube_M1);
    blankTube(Tube_M2);

    while (button3Flag != 1)
    {
        if (button1Flag > 0)
        {
            number++;
            number = (number > maximum) ? minimum : number;
            button1Flag = 0;
        }

        if (button2Flag > 0)
        {
            number--;
            number = (number < minimum) ? maximum : number;
            button2Flag = 0;
        }

        if (tubeConfig == 1)
        {
            blankTube(Tube_H1);
            blankTube(Tube_H2);
            delay(300);
            sprintf(buffer,"%02d", number);
            displayNumber(Tube_H1, buffer[0]-48);
            displayNumber(Tube_H2, buffer[1]-48);
            delay(300);
        }
        else if (tubeConfig == 2)
        {
            blankTube(Tube_M1);
            blankTube(Tube_M2);
            delay(300);
            sprintf(buffer,"%02d", number);
            displayNumber(Tube_M1, buffer[0]-48);
            displayNumber(Tube_M2, buffer[1]-48);
            delay(300);
        }
        else if (tubeConfig == 3)
        {
            blankTube(Tube_H2);
            delay(300);
            sprintf(buffer,"%01d", number);
            displayNumber(Tube_H2, buffer[0]-48);
            delay(300);
        }

    }

    button3Flag = 0;

    return number;
}

void initRTC(int restart)
{
    //
    // Initializes the internal RTC on the micro
    //

    /* Enable the PWR clock */
    RCC_APB1PeriphClockCmd(RCC_APB1Periph_PWR, ENABLE);
    /* Allow access to RTC */
    PWR_BackupAccessCmd(ENABLE);

    if (restart)
    {
        //Do this part only if the user chose to set the date/time
        RCC_BackupResetCmd(ENABLE);
        RCC_BackupResetCmd(DISABLE);

        //RCC_LSICmd(ENABLE);
        RCC_LSEConfig(RCC_LSE_ON);

        /* Wait until LSE is ready */
        while (RCC_GetFlagStatus(RCC_FLAG_LSERDY) == RESET);

        /* RTC Clock Source Selection */
        RCC_RTCCLKConfig(RCC_RTCCLKSource_LSE);

        /* Enable the RTC */
        RCC_RTCCLKCmd(ENABLE);

        RTC_WaitForSynchro();

        RTC_InitTypeDef RTC_InitStruct;
        RTC_StructInit(&RTC_InitStruct);
        RTC_InitStruct.RTC_HourFormat = RTC_HourFormat_24;
        RTC_Init(&RTC_InitStruct);
    }
    else
    {
        RTC_WaitForSynchro();
    }
}

void setRTC()
{
    int hours = numbericInput(1, 0, 23);
    int minutes = numbericInput(2, 0, 59);

    initRTC(1);

    RTC_TimeTypeDef RTC_TimeStruct;
    RTC_TimeStruct.RTC_Hours = hours;
    RTC_TimeStruct.RTC_Minutes = minutes;
    RTC_TimeStruct.RTC_Seconds = 0;
    RTC_SetTime(RTC_Format_BIN,&RTC_TimeStruct);

    RTC_DateTypeDef RTC_DateStruct;
    RTC_DateStruct.RTC_WeekDay = 1;
    RTC_DateStruct.RTC_Date = 1;
    RTC_DateStruct.RTC_Month = 1;
    RTC_DateStruct.RTC_Year = 15;
    RTC_SetDate(RTC_Format_BIN,&RTC_DateStruct);
}

void initRTCAlarm()
{
    //
    // Sets the RTC alarm that is used to toggle between clock/temperature display
    //

    EXTI_InitTypeDef EXTI_InitStructure;
    EXTI_ClearITPendingBit(EXTI_Line17);
    EXTI_InitStructure.EXTI_Line = EXTI_Line17;
    EXTI_InitStructure.EXTI_Mode = EXTI_Mode_Interrupt;
    EXTI_InitStructure.EXTI_Trigger = EXTI_Trigger_Rising;
    EXTI_InitStructure.EXTI_LineCmd = ENABLE;
    EXTI_Init(&EXTI_InitStructure);

    /* Enable the RTC Alarm Interrupt */
    NVIC_InitTypeDef NVIC_InitStructure;
    NVIC_InitStructure.NVIC_IRQChannel = RTC_IRQn;
    NVIC_InitStructure.NVIC_IRQChannelPriority = 0;
    NVIC_InitStructure.NVIC_IRQChannelCmd = ENABLE;
    NVIC_Init(&NVIC_InitStructure);

    PWR_BackupAccessCmd(ENABLE);
    RTC_WriteProtectionCmd(DISABLE);

    RTC_AlarmCmd(RTC_Alarm_A, DISABLE);

    RTC_AlarmTypeDef alrm;
    alrm.RTC_AlarmDateWeekDaySel = RTC_AlarmDateWeekDaySel_WeekDay;
    alrm.RTC_AlarmMask = RTC_AlarmMask_All;


    RTC_SetAlarm(RTC_Format_BIN, RTC_Alarm_A, &alrm);
    RTC_AlarmCmd(RTC_Alarm_A, ENABLE);

    /* Enable Alarm interrupt */
    RTC_ITConfig(RTC_IT_ALRA, ENABLE);

    RTC_WriteProtectionCmd(ENABLE);
}

void setAutoPower()
{
    autoPowerOnEnabled = numbericInput(3, 0, 1);
    RTC_WriteBackupRegister(RTC_BKP_DR0, autoPowerOnEnabled);
    if (!autoPowerOnEnabled)
    {
        return;
    }

    autoPowerOffHours = numbericInput(1, 0, 23);
    autoPowerOffMinutes = numbericInput(2, 0, 59);
    RTC_WriteBackupRegister(RTC_BKP_DR3, autoPowerOffHours);
    RTC_WriteBackupRegister(RTC_BKP_DR4, autoPowerOffMinutes);

    autoPowerOnHours = numbericInput(1, 0, 23);
    autoPowerOnMinutes = numbericInput(2, 0, 59);
    RTC_WriteBackupRegister(RTC_BKP_DR1, autoPowerOnHours);
    RTC_WriteBackupRegister(RTC_BKP_DR2, autoPowerOnMinutes);
}

void initButtons()
{
    //
    // Configures the EXTI and NVIC to receive interrupts
    //

    RCC_AHBPeriphClockCmd(RCC_AHBPeriph_GPIOB, ENABLE);
    GPIO_InitTypeDef GPIO_InitStructure;
    GPIO_InitStructure.GPIO_Mode = GPIO_Mode_IN;
    GPIO_InitStructure.GPIO_PuPd = GPIO_PuPd_UP;
    GPIO_InitStructure.GPIO_Pin = GPIO_Pin_13|GPIO_Pin_14|GPIO_Pin_15;
    GPIO_Init(GPIOB, &GPIO_InitStructure);

    RCC_APB2PeriphClockCmd(RCC_APB2Periph_SYSCFG, ENABLE);
    SYSCFG_EXTILineConfig(EXTI_PortSourceGPIOB, EXTI_PinSource13);
    SYSCFG_EXTILineConfig(EXTI_PortSourceGPIOB, EXTI_PinSource14);
    SYSCFG_EXTILineConfig(EXTI_PortSourceGPIOB, EXTI_PinSource15);

    EXTI_InitTypeDef EXTI_struct;
    EXTI_struct.EXTI_Line = EXTI_Line13 | EXTI_Line14 | EXTI_Line15;
    EXTI_struct.EXTI_Mode = EXTI_Mode_Interrupt;
    EXTI_struct.EXTI_Trigger = EXTI_Trigger_Falling;
    EXTI_struct.EXTI_LineCmd = ENABLE;
    EXTI_Init(&EXTI_struct);

    //Enable NVIC
    NVIC_InitTypeDef NVIC_InitStructure;
    NVIC_InitStructure.NVIC_IRQChannel = EXTI4_15_IRQn;
    NVIC_InitStructure.NVIC_IRQChannelPriority = 1;
    NVIC_InitStructure.NVIC_IRQChannelCmd = ENABLE;
    NVIC_Init(&NVIC_InitStructure);
}

int main(void)
{
    init_essentials_time();
    initRTC(0);
    initRTCAlarm();
    initButtons();
    DHT22TimerInit();

    RCC_AHBPeriphClockCmd(RCC_AHBPeriph_GPIOC, ENABLE);
    RCC_AHBPeriphClockCmd(RCC_AHBPeriph_GPIOF, ENABLE);
    RCC_AHBPeriphClockCmd(RCC_AHBPeriph_GPIOD, ENABLE);
    RCC_AHBPeriphClockCmd(RCC_AHBPeriph_GPIOB, ENABLE);
    RCC_AHBPeriphClockCmd(RCC_AHBPeriph_GPIOA, ENABLE);

    GPIO_InitTypeDef GPIO_InitStructure_A;
    GPIO_InitStructure_A.GPIO_Mode = GPIO_Mode_OUT;
    GPIO_InitStructure_A.GPIO_Speed = GPIO_Speed_2MHz;
    GPIO_InitStructure_A.GPIO_OType = GPIO_OType_PP;
    GPIO_InitStructure_A.GPIO_PuPd = GPIO_PuPd_NOPULL;

    GPIO_InitTypeDef GPIO_InitStructure_B = GPIO_InitStructure_A;
    GPIO_InitTypeDef GPIO_InitStructure_C = GPIO_InitStructure_A;
    GPIO_InitTypeDef GPIO_InitStructure_D = GPIO_InitStructure_A;
    GPIO_InitTypeDef GPIO_InitStructure_F = GPIO_InitStructure_A;

    GPIO_InitStructure_A.GPIO_Pin = GPIO_Pin_3 | GPIO_Pin_4 | GPIO_Pin_5 | GPIO_Pin_6 | GPIO_Pin_7 | GPIO_Pin_8 | GPIO_Pin_9 | GPIO_Pin_10 | GPIO_Pin_11 | GPIO_Pin_12 | GPIO_Pin_15;
    GPIO_InitStructure_B.GPIO_Pin = GPIO_Pin_0 | GPIO_Pin_1 | GPIO_Pin_2 | GPIO_Pin_3 | GPIO_Pin_4 | GPIO_Pin_5 | GPIO_Pin_6 | GPIO_Pin_10;
    GPIO_InitStructure_C.GPIO_Pin = GPIO_Pin_4 | GPIO_Pin_5 | GPIO_Pin_8 | GPIO_Pin_9 | GPIO_Pin_10 | GPIO_Pin_11 | GPIO_Pin_12;
    GPIO_InitStructure_D.GPIO_Pin = GPIO_Pin_2;
    GPIO_InitStructure_F.GPIO_Pin = GPIO_Pin_4 | GPIO_Pin_5;

    GPIO_Init(GPIOC, &GPIO_InitStructure_C);
    GPIO_Init(GPIOF, &GPIO_InitStructure_F);
    GPIO_Init(GPIOD, &GPIO_InitStructure_D);
    GPIO_Init(GPIOB, &GPIO_InitStructure_B);
    GPIO_Init(GPIOA, &GPIO_InitStructure_A);

    autoPowerOnEnabled = RTC_ReadBackupRegister(RTC_BKP_DR0);
    autoPowerOnHours = RTC_ReadBackupRegister(RTC_BKP_DR1);
    autoPowerOnMinutes = RTC_ReadBackupRegister(RTC_BKP_DR2);
    autoPowerOffHours = RTC_ReadBackupRegister(RTC_BKP_DR3);
    autoPowerOffMinutes = RTC_ReadBackupRegister(RTC_BKP_DR4);

    RTC_TimeTypeDef RTC_TimeStruct;
    char time_buff[4];
    unsigned int lastTempDisplay = millis() + 30000;
    int temperature = 0;

    while(1)
    {
        RTC_GetTime(RTC_Format_BIN, &RTC_TimeStruct);

        if (state == State_Clock)
        {
            sprintf(time_buff,"%02d", RTC_TimeStruct.RTC_Hours);
            displayNumber(Tube_H1, time_buff[0]-48);
            displayNumber(Tube_H2, time_buff[1]-48);

            sprintf(time_buff,"%02d", RTC_TimeStruct.RTC_Minutes);
            displayNumber(Tube_M1, time_buff[0]-48);
            displayNumber(Tube_M2, time_buff[1]-48);
        }
        else if (state == State_Off)
        {
            blankTube(Tube_H1);
            blankTube(Tube_H2);
            blankTube(Tube_M1);
            blankTube(Tube_M2);
        }
        else if (state == State_Temperature)
        {
            DHT22_Read();

            #ifdef TEMP_SENSOR_DHT11
            temperature = DHT11getTemperature();
            #elif defined TEMP_SENSOR_DHT22
            temperature = DHT22getTemperature();
            #endif

            blankTube(Tube_H1);
            blankTube(Tube_M1);

            sprintf(time_buff,"%02d", temperature);
            displayNumber(Tube_M2, time_buff[0]-48);
            displayNumber(Tube_H2, time_buff[1]-48);

            delay(5000);

            state = State_Clock;
        }

        // Auto power button handling
        // Sets the time for auto power off and auto power down
        if (button1Flag == 1 && abs(millis()-button1PressStart) > 300 && GPIO_ReadInputDataBit(Pin_Button_1) == RESET)
        {
            button1Flag = 0;
            setAutoPower();
        }
        else if (button1Flag == 1 && GPIO_ReadInputDataBit(Pin_Button_1) != RESET)
        {
            button1Flag = 0;
        }

        // Display off button handling
        // Turns the display off or on when pressed - useful at nights
        // Button needs to be held down for more than 0.3s
        if (button2Flag == 1 && abs(millis()-button2PressStart) > 300 && GPIO_ReadInputDataBit(Pin_Button_2) == RESET)
        {
            state = (state == State_Clock || state == State_Temperature) ? State_Off : State_Clock;
            button2Flag = 0;
            delay(500);
        }
        else if (button2Flag == 1 && GPIO_ReadInputDataBit(Pin_Button_2) != RESET)
        {
            button2Flag = 0;
        }

        // Set time button handling
        // Button needs to be held down for more than 4s to set the time
        if (button3Flag == 1 && abs(millis()-button3PressStart) > 4000 && GPIO_ReadInputDataBit(Pin_Button_3) == RESET)
        {
            button3Flag = 0;
            setRTC();
            state = State_Clock;
        }
        else if (button3Flag == 1 && GPIO_ReadInputDataBit(Pin_Button_3) != RESET)
        {
            button3Flag = 0;
        }

        #ifdef TEMP_SENSOR_ENABLE
        if (secondsPassed > 30)
        {
            if (state == State_Clock)
            {
                state = State_Temperature;
            }
            secondsPassed = 0;
        }
        #endif

        if (autoPowerOnEnabled && autoPowerOffHours == RTC_TimeStruct.RTC_Hours && autoPowerOffMinutes == RTC_TimeStruct.RTC_Minutes && RTC_TimeStruct.RTC_Seconds < 15)
        {
            state = State_Off;
        }
        if (autoPowerOnEnabled && autoPowerOnHours == RTC_TimeStruct.RTC_Hours && autoPowerOnMinutes == RTC_TimeStruct.RTC_Minutes && RTC_TimeStruct.RTC_Seconds < 15)
        {
            state = State_Clock;
        }
    }
}

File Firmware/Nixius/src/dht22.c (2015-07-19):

/*
DHT 22 humidity and temperature sensor library

    Copyright (C) 2013  Fabio Angeletti - fabio.angeletti89@gmail.com

    See attached license.txt file

*/

/* includes --------------------------------------------------------- */
#include "dht22.h"

/* functions -------------------------------------------------------- */

/*
  configure DHT22_DATA as input
 */
void DHT22TimerInit(void) {
  uint16_t PrescalerValue = 0;

  TIM_TimeBaseInitTypeDef   TIM_TimeBaseStructure;
  TIM_OCInitTypeDef         TIM_OCInitStructure;

  /* TIM3 clock enable */
  RCC_APB1PeriphClockCmd(RCC_APB1Periph_TIM3, ENABLE);

  TIM_TimeBaseStructInit(&TIM_TimeBaseStructure);
  TIM_OCStructInit(&TIM_OCInitStructure);

  /* Compute the prescaler value */
  PrescalerValue = (uint16_t) (SystemCoreClock / 1000000) - 1;

  /* Time base configuration */
  TIM_TimeBaseStructure.TIM_Period = 65535 - 1;      //in uSecs
  TIM_TimeBaseStructure.TIM_Prescaler = PrescalerValue;
  TIM_TimeBaseStructure.TIM_ClockDivision = 0;
  TIM_TimeBaseStructure.TIM_CounterMode = TIM_CounterMode_Up;
  TIM_TimeBaseInit(TIM3, &TIM_TimeBaseStructure);

  TIM_Cmd(TIM3, ENABLE);
}

/*
  configure DHT22_DATA as input
 */
void DHT22pinIn(void){
  GPIO_InitTypeDef GPIO_InitStructure;

  GPIO_InitStructure.GPIO_Pin =  DHT22_DATA_PIN;
  GPIO_InitStructure.GPIO_Speed = GPIO_Speed_50MHz;
  GPIO_InitStructure.GPIO_Mode = GPIO_Mode_IN;
  GPIO_InitStructure.GPIO_OType = GPIO_OType_PP;
  GPIO_InitStructure.GPIO_PuPd = GPIO_PuPd_UP;
  GPIO_Init(DHT22_GPIO, &GPIO_InitStructure);
}


/*
  configure DHT22_DATA as output
 */
void DHT22pinOut(void){
  GPIO_InitTypeDef GPIO_InitStructure;

  GPIO_InitStructure.GPIO_Pin =  DHT22_DATA_PIN;
  GPIO_InitStructure.GPIO_Speed = GPIO_Speed_50MHz;
  GPIO_InitStructure.GPIO_Mode = GPIO_Mode_OUT;
  GPIO_InitStructure.GPIO_OType = GPIO_OType_PP;
  GPIO_InitStructure.GPIO_PuPd = GPIO_PuPd_UP;
  GPIO_Init(DHT22_GPIO, &GPIO_InitStructure);
}


void DHT22_Init(void){
  RCC_AHBPeriphClockCmd(RCC_AHBPeriph_GPIOB, ENABLE);
  DHT22pinOut();

  /* hold DHT22 in standby state */
  GPIO_SetBits(DHT22_GPIO, DHT22_DATA_PIN);
}


void DHT22_Read(void){
  uint8_t dataIndex = 0;
  uint8_t counter = 7;
  uint8_t currByte = 0;
  uint8_t index = 0;
  uint32_t startTime = 0;

  /* reset data holder */
  for(index=0; index < 6; index++){
    DHT22data[index] = 0x00;
  }

  /* mcu sends start signal to sensor */
  DHT22pinOut();
  GPIO_ResetBits(DHT22_GPIO, DHT22_DATA_PIN);
  TIM_SetCounter(DHT22_TIM, 0);

  /* wait for at least 20 mSecs */
  while(TIM_GetCounter(DHT22_TIM) < 20000);

  /* switch to input and wait for sensor response */
  DHT22pinIn();
  while(GPIO_ReadInputDataBit(DHT22_GPIO, DHT22_DATA_PIN));

  /* DHT22 sends response signal */
  while(!GPIO_ReadInputDataBit(DHT22_GPIO, DHT22_DATA_PIN));
  while(GPIO_ReadInputDataBit(DHT22_GPIO, DHT22_DATA_PIN));

  /* DHT22 sends, finally, data */
  for (dataIndex=0; dataIndex<40; dataIndex++) {
    TIM_SetCounter(DHT22_TIM, 0);
    while(!GPIO_ReadInputDataBit(DHT22_GPIO, DHT22_DATA_PIN));
    startTime = TIM_GetCounter(DHT22_TIM);
    while(GPIO_ReadInputDataBit(DHT22_GPIO, DHT22_DATA_PIN));

    if ((TIM_GetCounter(DHT22_TIM) - startTime) > 40){
      DHT22data[currByte] |= (1 << counter);
    }

    if (counter == 0) {   // next byte?
      counter = 7;        // restart at MSB
      currByte++;         // next byte!
    } else {
      counter--;
    }

  }
}


float DHT22getTemperature(void){
  float retVal;

  retVal = DHT22data[2];
  retVal = DHT22data[2] & 0x7F;
  retVal *= 256;
  retVal += DHT22data[3];
  retVal /= 10;

  if (DHT22data[2] & 0x80)
    retVal *= -1;

  return retVal;
}


float DHT22getHumidity(void){
  float retVal;

  retVal = DHT22data[0];
  retVal *= 256;
  retVal += DHT22data[1];
  retVal /= 10;

  return retVal;
}

float DHT11getTemperature(void){
  float retVal;

  retVal = DHT22data[2];

  return retVal;
}


float DHT11getHumidity(void){
  float retVal;

  retVal = DHT22data[0];

  return retVal;
}


float convertCtoF(float cTemperature){
  return cTemperature * 9 / 5 + 32;
}

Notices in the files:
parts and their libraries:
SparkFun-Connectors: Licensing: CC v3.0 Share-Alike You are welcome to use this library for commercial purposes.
